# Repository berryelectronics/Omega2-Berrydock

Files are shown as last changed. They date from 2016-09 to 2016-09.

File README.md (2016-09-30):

# Berrydock Mini



The first one of the series, small but packs a bunch of stuff!
* Onboard Ethernet Jack with Passive PoE cabality (up to 24V)
* Onboard Lithium battery connector with 5V Booster and Charging circuit integrated
* Pinout to most of the GPIO
* Feedback to the Omega2 for when the battery is running low or when it is fully charged
* Onboard USB-to-Serial Converter (CP2102)
* Only 5x5cm in size!

Some renders of the PCB

Front side of the PCB Render

Back side of the PCB

The Schematic can also be viewed inside the project folder

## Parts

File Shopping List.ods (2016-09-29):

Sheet: BoM One Piece
Type | Value/Name | Amount | Price One | Price All | Zwischensumme
IC | ACT4088 | 1 | 0,31 € | 0,31 €
IC | DW01-P | 1 | 0,04 € | 0,04 €
IC | FS8205A | 1 | 0,04 € | 0,04 €
IC | MCP73831 | 1 | 0,11 € | 0,11 €
IC | L6920DCTR | 1 | 0,55 € | 0,55 €
IC | USBLC6-2 | 2 | 0,18 € | 0,36 €
IC | H1260NL | 1 | 0,27 € | 0,27 €
IC | TD6811 | 1 | 0,16 € | 0,16 €
IC | CP2102 | 1 | 0,85 € | 0,85 € | 2,69 €
Resistor | 10K 0603 | 8 | 0,00 € | 0,02 €
Resistor | 150K 0603 | 1 | 0,00 € | 0,00 €
Resistor | 28.7K 0603 | 1 | 0,00 € | 0,00 €
Resistor | 1K 0603 | 3 | 0,00 € | 0,01 €
Resistor | 2K 0603 | 5 | 0,00 € | 0,02 €
Resistor | 20K 0603 | 1 | 0,00 € | 0,00 €
Resistor | 200K 0603 | 1 | 0,00 € | 0,00 €
Resistor | 1M 0603 | 1 | 0,00 € | 0,00 €
Resistor | 3K 0603 | 5 | 0,00 € | 0,02 €
Resistor | 75R 0603 | 2 | 0,00 € | 0,01 €
Resistor | 0R 0603 | 4 | 0,00 € | 0,02 €
Resistor | 100R 0603 | 1 | 0,00 € | 0,00 €
Resistor | 49.9R 0603 | 4 | 0,01 € | 0,02 € | 0,13 €
Capacitor | 10uF 50V 1206 | 4 | 0,02 € | 0,08 €
Capacitor | 22nF 0603 | 1 | 0,00 € | 0,00 €
Capacitor | 4.7uF 0603 | 6 | 0,02 € | 0,12 €
Capacitor | 100nF 0603 | 7 | 0,00 € | 0,03 €
Capacitor | 1uF 0603 | 2 | 0,01 € | 0,02 €
Capacitor | 1nF 2kV 1206 | 1 | 0,03 € | 0,03 €
Capacitor | 47uF 0805 | 1 | 0,02 € | 0,02 € | 0,30 €
Inductor | 10uF 1A CD43 | 1 | 0,08 € | 0,08 €
Inductor | 4.7uH 1A CD32 | 2 | 0,06 € | 0,12 € | 0,20 €
Diode | M7 1N4007 | 1 | 0,01 € | 0,01 €
Diode | D240A-13-F | 1 | 0,17 € | 0,17 €
Diode | LED Red 0805 | 2 | 0,01 € | 0,02 € | 0,20 €
Fuse | 1A 8V 1812 | 1 | 0,10 € | 0,10 € | 0,10 €
Connector | 2mm Female 40 Pin | 1 | 0,17 € | 0,17 €
Connector | 2.54mm Male 40 Pin | 1 | 0,55 € | 0,55 €
Connector | S2B-PH-SM4-TB JST LiPo | 1 | 0,25 € | 0,25 €
Connector | Ethernet Jack | 1 | 0,24 € | 0,24 €
Connector | USB Type A 90 Degrees | 1 | 0,10 € | 0,10 €
Connector | Micro USB SMD | 1 | 0,20 € | 0,20 € | 1,51 €
Miscellanious | SMD Tactile Switch | 1 | 0,05 € | 0,05 €
Miscellanious | SMD Switch | 1 | 0,10 € | 0,10 € | 0,15 €
PCB | 5x5cm | 1 | 2,00 € | 2,00 € | 2,00 €
 |  |  |  | 7,28 €
 |  |  | Gesamt | 8,00 €

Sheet: Order List (x20)
Type | Name | Amount | Price All | Price One | Link
IC | ACT4088 | 10 | 3,09 | 0,309 | https://de.aliexpress.com/item/10PCS-LOT-ACT4088US-T-ACT4088US-ACT4088-SOT23-6-DC-DC-chip/32698768524.html
IC | FS8205 | 50 | 1,65 | 0,033 | https://de.aliexpress.com/item/10PCS-free-shipping-100-new-original-new-original-DW01D-FS8205-SOT23-6-lithium-battery-protection-IC/1676832825.html
IC | DW01 | 50 | 1,65 | 0,033 | https://de.aliexpress.com/item/10PCS-free-shipping-100-new-original-new-original-DW01D-FS8205-SOT23-6-lithium-battery-protection-IC/1676832825.html
IC | MCP73831 | 20 | 2,08 | 0,104 | https://de.aliexpress.com/item/20PCS-MCP73831T-2ACI-OT-MCP73831T-2ACI-SOT-23-5-MCP73831/32239785824.html
IC | L6920DCTR | 10 | 5,43 | 0,543 | https://de.aliexpress.com/item/10-PCS-lot-L6920-L6920D-L6920DCTR-prints-6920-ST/32675590284.html
IC | USBLC6-2 | 20 | 3,5 | 0,175 | https://de.aliexpress.com/item/Free-shipping-20pcs-lot-SMT-SOT-23-6-chips-USBLC6-2-new-original/32518640742.html
IC | H1260NL | 20 | 5,25 | 0,2625 | https://de.aliexpress.com/item/H1260NL-genuine-new-original-100-PULSE-SMT-SOP16/32519209228.html
IC | TD6811 | 20 | 3,17 | 0,1585 | https://de.aliexpress.com/item/20PCS-TD6811-6811-SOT23-5/32463696690.html
IC | CP2102 | 10 | 8,41 | 0,841 | https://de.aliexpress.com/item/Free-Shipping-10pcs-USB-interface-control-chip-CP2102-QFN28/1062388544.html
Resistor | 10K 0603 | 100 | 0,23 | 0,0023 | https://de.aliexpress.com/item/0603-SMD-Resistor-1-10K-ohm-5000pcs-lot/32308120947.html
Resistor | 150K 0603 | 100 | 0,23 | 0,0023 | https://de.aliexpress.com/item/0603-SMD-Resistor-1-150K-ohm-5000pcs-lot/32307046476.html
Resistor | 28.7K 0603 | 100 | 0,23 | 0,0023 | https://de.aliexpress.com/item/0603-SMD-Resistor-1-28-7K-ohm-5000pcs-lot/32306337804.html
Resistor | 1K 0603 | 100 | 0,23 | 0,0023 | https://de.aliexpress.com/item/0603-SMD-Resistor-1-1K-ohm-5000pcs-lot/32306337400.html
Resistor | 2K 0603 | 100 | 0,23 | 0,0023 | https://de.aliexpress.com/item/0603-SMD-Resistor-1-2K-ohm-5000pcs-lot/32308160767.html
Resistor | 20K 0603 | 100 | 0,23 | 0,0023 | https://de.aliexpress.com/item/0603-SMD-Resistor-1-20K-ohm-5000pcs-lot/32307054013.html
Resistor | 200K 0603 | 100 | 0,23 | 0,0023 | https://de.aliexpress.com/item/0603-SMD-Resistor-1-200K-ohm-5000pcs-lot/32308144804.html
Resistor | 1M 0603 | 100 | 0,23 | 0,0023 | https://de.aliexpress.com/item/0603-SMD-Resistor-1-1M-ohm-5000pcs-lot/32307407217.html
Resistor | 3K 0603 | 100 | 0,23 | 0,0023 | https://de.aliexpress.com/item/0603-SMD-Resistor-1-3K-ohm-5000pcs-lot/32308160800.html
Resistor | 75R 0603 | 100 | 0,35 | 0,0035 | https://de.aliexpress.com/item/Free-shipping-500pcs-RES-ORIGINAL-SMD-Resistor-1-0603-75R-75-OHMS-chip-resistor-1-10w/32260381157.html
Resistor | 0R 0603 | 100 | 0,35 | 0,0035 | https://de.aliexpress.com/item/Free-shipping-100pcs-RES-ORIGINAL-SMD-Resistor-1-0603-0R-0-OHMS-chip-resistor-1-10W/32506782798.html
Resistor | 100R 0603 | 100 | 0,35 | 0,0035 | https://de.aliexpress.com/item/Free-shipping-500pcs-RES-ORIGINAL-SMD-Resistor-1-0603-100R-100-OHMS-chip-resistor-1-10W/32262485248.html
Resistor | 49.9R 0603 | 100 | 0,55 | 0,0055 | https://de.aliexpress.com/item/100pcs-lot-SMD-Chip-Resistor-1-0603-49-9R-49-9-OHMS-1-10W-100-YAGEO/32571843113.html
Capacitor | 10uF 50V 1206 | 200 | 2,8 | 0,014 | https://de.aliexpress.com/item/Free-Shipping-1206-smd-capacitor-3216-10UF-106-50V/1889689228.html
Capacitor | 22nF 0603 | 100 | 0,34 | 0,0034 | https://de.aliexpress.com/item/100pcs-lot-22nF-Y5V-Error-20-50V-0603-smd-capacitor/32319892152.html
Capacitor | 4.7uF 0603 | 100 | 1,23 | 0,0123 | https://de.aliexpress.com/item/100pcs-lot-4-7uF-X5R-Error-10-16V-0603-smd-capacitor/32319876555.html
Capacitor | 100nF 0603 | 100 | 0,34 | 0,0034 | https://de.aliexpress.com/item/100pcs-lot-100nF-X7R-Error-10-50V-0603-smd-capacitor/32318089455.html
Capacitor | 1uF 0603 | 100 | 0,92 | 0,0092 | https://de.aliexpress.com/item/100pcs-lot-1uF-X5R-Error-10-16V-0603-smd-capacitor/32319876550.html
Capacitor | 1nF 2kV 1206 | 100 | 2,45 | 0,0245 | https://de.aliexpress.com/item/100pcs-lot-1nF-X7R-Error10-2KV-1206-smd-capacitor/32319991021.html
Capacitor | 47uF 0805 | 100 | 1,86 | 0,0186 | https://de.aliexpress.com/item/Free-shipping-005-SMD-capacitor-47uf-16V-476K-100PCS/32374775645.html
Inductor | 10uF 1A CD43 | 50 | 3,74 | 0,0748 | https://de.aliexpress.com/item/50PCS-LOT-CD43-10UH-100-1A-Wire-Wound-Chip-Inductors/32310490700.html
Inductor | 4.7uH 1A CD32 | 100 | 5,7 | 0,057 | https://de.aliexpress.com/item/Free-ship-100PCS-High-Quality-CD32-4-7UH-4R7-1A-Winding-SMD-Power-Inductor-Wire-Wound/32600295471.html
Diode | M7 1N4007 | 50 | 0,48 | 0,0096 | https://de.aliexpress.com/item/Free-shiiping-50PCS-DIODE-M7-1N4007-SMD-1A-1000V-Rectifier-Diode-A027/32586502630.html
Diode | D240A-13-F | 20 | 3,29 | 0,1645 | https://de.aliexpress.com/item/B240A-B240A-13-F-only-do-import-new-original-spot-ICQ3/32715096810.html
Diode | LED Red 0805 | 100 | 0,9 | 0,009 | https://de.aliexpress.com/item/Smart-Electronics-100pcs-lot-Super-Bright-0805-Red-Lighting-SMD-Led-Diode-620-625nm-120-150MCD/32592136800.html
Fuse | 1A 8V 1812 | 100 | 8,32 | 0,0832 | https://de.aliexpress.com/item/1812-8V-1A-1-1A-SMD-patch-self-recovery-fuse-all/32600969766.html
Connector | 2mm Female 40 Pin | 10 | 1,63 | 0,163 | https://de.aliexpress.com/item/10PCS-LOT-Female-Pin-Header-Strip-1-40-Pin-2mm-Single-Row-Female-Pin-Header/32692137257.html
Connector | 2.54mm Male 40 Pin | 10 | 0,55 | 0,055 | https://de.aliexpress.com/item/Free-Shipping-40Pin-2-54mm-male-Single-Row-40P-single-Row-20pcs-40-pins-pin-header/1702073435.html
Connector | S2B-PH-SM4-TB JST LiPo | 50 | 11,57 | 0,2314 | https://de.aliexpress.com/item/S2B-PH-SM4-TB-LF-SN/32658848052.html
Connector | Ethernet Jack | 10 | 2,36 | 0,236 | https://de.aliexpress.com/item/10Pcs-Female-RJ45-Ethernet-PCB-Modular-Terminal-Socket-Connector-Jack/32275923385.html
Connector | USB Type A 90 Degrees | 50 | 4,01 | 0,0802 | https://de.aliexpress.com/item/A-Female-USB-socket-looper-USB-A-type-connector-female-90-degree-bend-feet-Free-shipping/32712708223.html
Connector | Micro USB SMD | 20 | 3,8 | 0,19 | https://de.aliexpress.com/item/20PCS-SMD-MICRO-MINI-USB-5-Pin-5pin-Female-for-mobile-phone-charging-power-connector/32292625613.html
Miscellanious | SMD Tactile Switch | 50 | 2,03 | 0,0406 | https://de.aliexpress.com/item/50PCS-2-4-3-5MM-mini-SMD-MP3-MP4-Key-switch-Push-button-switch-Side-SMD/32691696109.html
Miscellanious | SMD Switch | 50 | 4,99 | 0,0998 | https://de.aliexpress.com/item/50-PCS-DC-50V-0-3A-7-Pin-On-On-2-Position-1P2T-SPDT-SMD-Slide/32304561463.html
 |  |  | 101,21

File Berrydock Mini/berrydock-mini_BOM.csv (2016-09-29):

Reference | Value | Footprint | Count | Datasheet | FootprintLib
U5 | Omega2 | Omega2-Outline | 1 |  | Omega2-Berrydock
J1 | RJ45 | RJ45-SHIELDED | 1 |  | Omega2-Berrydock
C10 | 10uF/50V | C_1206 | 1 |  | Capacitors_SMD
D3 | B240A | DO-214AC.SMA | 1 |  | Omega2-Berrydock
L2 | 4.7uH | CD32 | 1 |  | Omega2-Berrydock
U8 | ACT4088 | SOT-23-6_Handsoldering | 1 |  | TO_SOT_Packages_SMD
R13 | R15 | R29 | R21 | R1 | R5 | R4 | R24 | 10K | R_0603_HandSoldering | 8 |  | Resistors_SMD
C13 | 22nF | C_0603 | 1 |  | Capacitors_SMD
R20 | 150K | R_0603_HandSoldering | 1 |  | Resistors_SMD
R19 | 28.7K | R_0603_HandSoldering | 1 |  | Resistors_SMD
C14 | C11 | C17 | C22 | C23 | 4.7uF | C_0603 | 5 |  | Capacitors_SMD
P3 | CONN_01X04 | PWR-SELECT | 1 |  | Omega2-Berrydock
U12 | DW01-P | SOT-23-6_Handsoldering | 1 |  | TO_SOT_Packages_SMD
U11 | FS8205A | TSSOP8 | 1 |  | Omega2-Berrydock
C15 | C12 | C21 | C4 | C5 | C19 | C20 | 100nF | C_0603 | 7 |  | Capacitors_SMD
R25 | 100R | R_0603_HandSoldering | 1 |  | Resistors_SMD
R18 | R23 | R10 | 1K | R_0603_HandSoldering | 3 |  | Resistors_SMD
U9 | MCP73831 | SOT-23-5 | 1 |  | TO_SOT_Packages_SMD
R16 | R27 | R36 | R35 | 2K | R_0603_HandSoldering | 4 |  | Resistors_SMD
D4 | D1 | Led_Small | LED_0805 | 2 |  | LEDs
U10 | L6920DC | MSOP8 | 1 |  | Omega2-Berrydock
L3 | 10uH | CD43 | 1 |  | Omega2-Berrydock
R14 | 20K | R_0603_HandSoldering | 1 |  | Resistors_SMD
C16 | 47uF | C_0805 | 1 |  | Capacitors_SMD
R17 | 200K | R_0603_HandSoldering | 1 |  | Resistors_SMD
P5 | USB_OTG | USB_Micro-B | 1 |  | Connect
U13 | U14 | USBLC6-2 | SOT32-6L | 2 |  | Omega2-Berrydock
R28 | R34 | 1M | R_0603_HandSoldering | 2 |  | Resistors_SMD
F1 | 1A/8V | FUSE-1812 | 1 |  | Omega2-Berrydock
SW1 | SWITCH_INV | SMD-SLIDESWITCH | 1 |  | Omega2-Berrydock
SW2 | BUTTON | SMD-BUTTON-2x4x3,5 | 1 |  | Omega2-Berrydock
R26 | R37 | R38 | 3K | R_0603_HandSoldering | 3 |  | Resistors_SMD
U4 | H1260NL | HL1260NL | 1 |  | Omega2-Berrydock
C8 | C18 | 1uF | C_0603 | 2 |  | Capacitors_SMD
R8 | R6 | R7 | R9 | 49.9R | R_0603 | 4 |  | Resistors_SMD
R12 | R11 | 75R | R_0603 | 2 |  | Resistors_SMD
C9 | 1nF/2kV | C_1206 | 1 |  | Capacitors_SMD
D2 | 1N4007-SMD | DO-214AC.SMA | 1 |  | Omega2-Berrydock
P6 | USB_A | USB_A | 1 |  | Connect
R32 | R33 | R30 | R31 | 0R | R_0603_HandSoldering | 4 |  | Resistors_SMD
U3 | TD6811 | SOT-23-5 | 1 |  | TO_SOT_Packages_SMD
L1 | 4.7uH/1A | CD32 | 1 |  | Omega2-Berrydock
C1 | C7 | 10uF | C_1206 | 2 |  | Capacitors_SMD
P4 | CONN_01X03 | JST-RIGHT-ANGLE | 1 |  | Omega2-Berrydock
P1 | CONN_01X16 | Pin_Header_Straight_1x16 | 1 |  | Pin_Headers
P2 | CONN_01X07 | Pin_Header_Straight_1x07 | 1 |  | Pin_Headers
R3 | 2K | R_0603 | 1 |  | Resistors_SMD
R2 | 3K | R_0603 | 1 |  | Resistors_SMD
U1 | CP2102 | QFN-28 | 1 |  | Omega2-Berrydock

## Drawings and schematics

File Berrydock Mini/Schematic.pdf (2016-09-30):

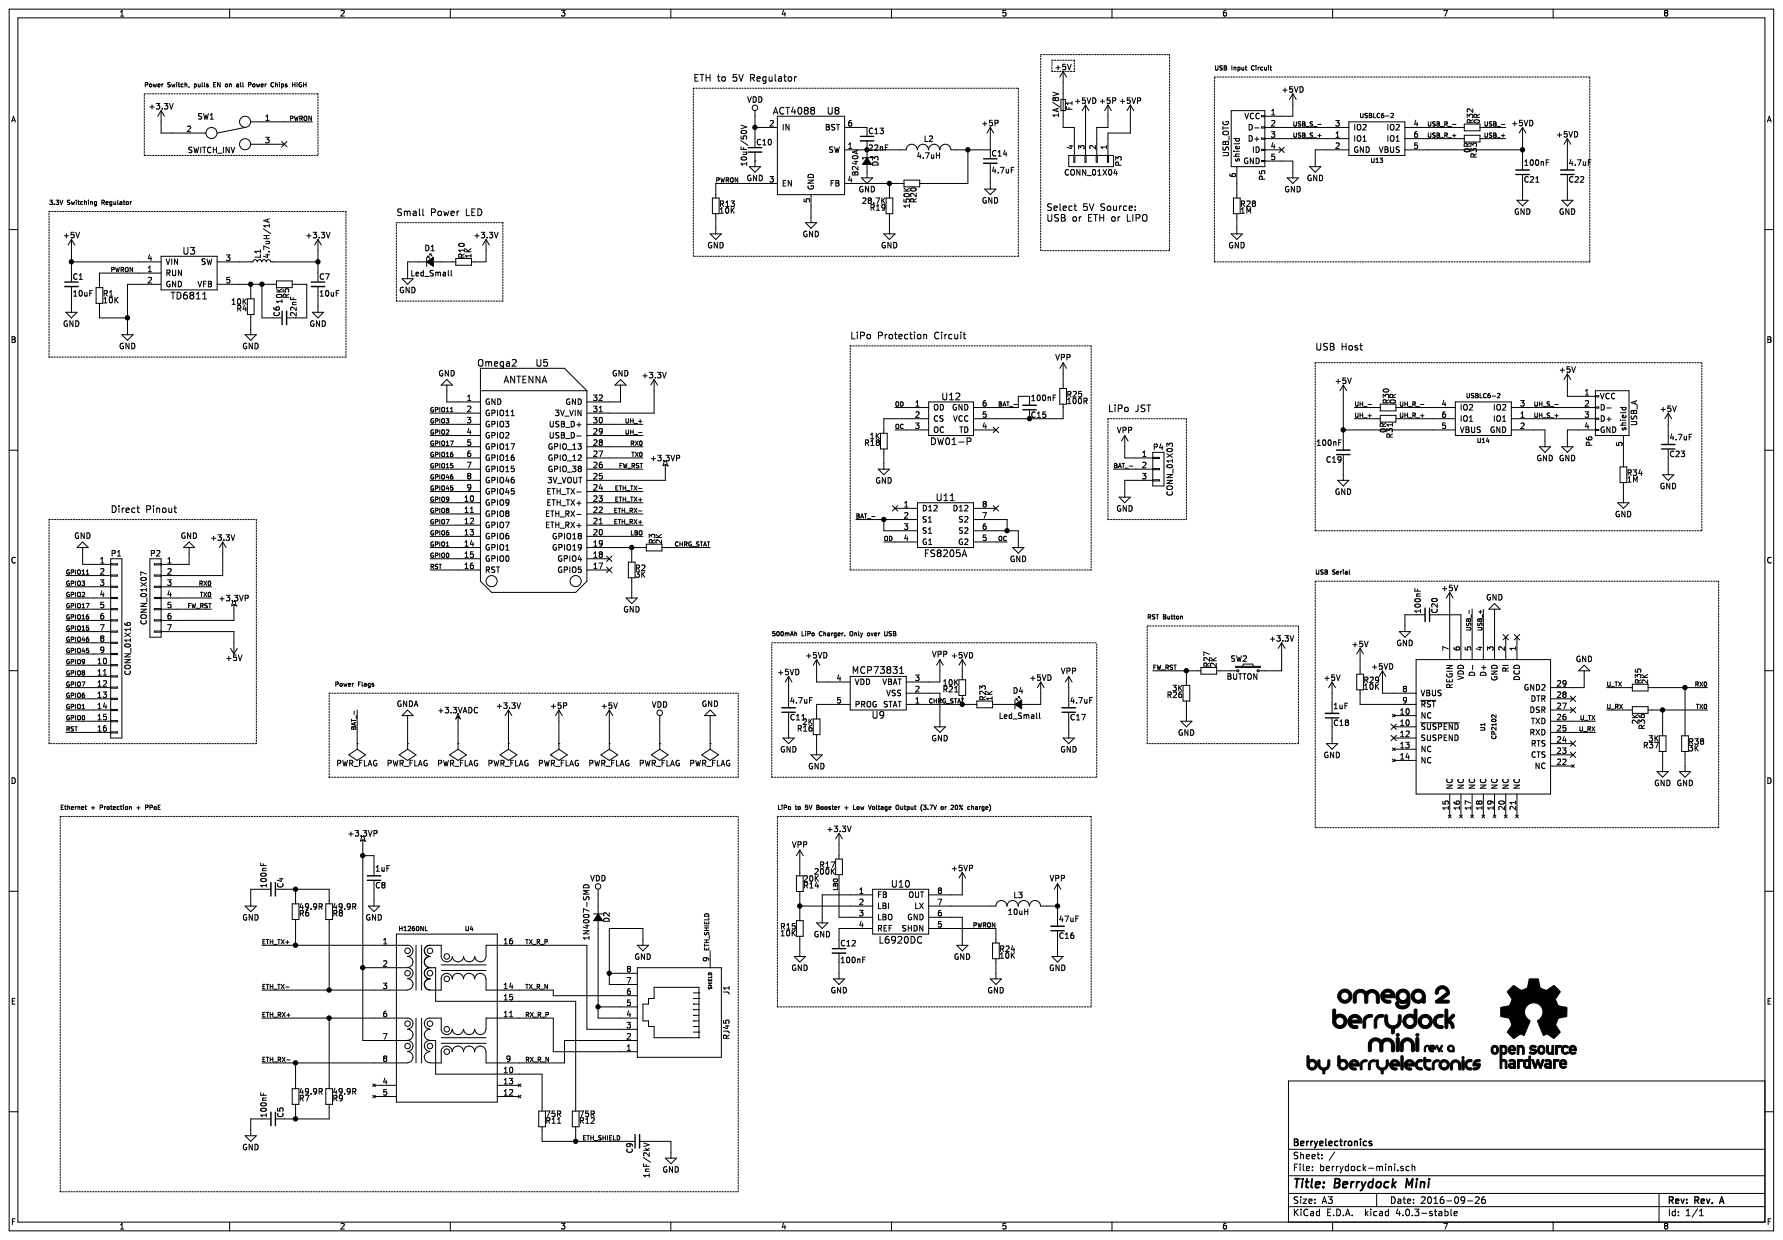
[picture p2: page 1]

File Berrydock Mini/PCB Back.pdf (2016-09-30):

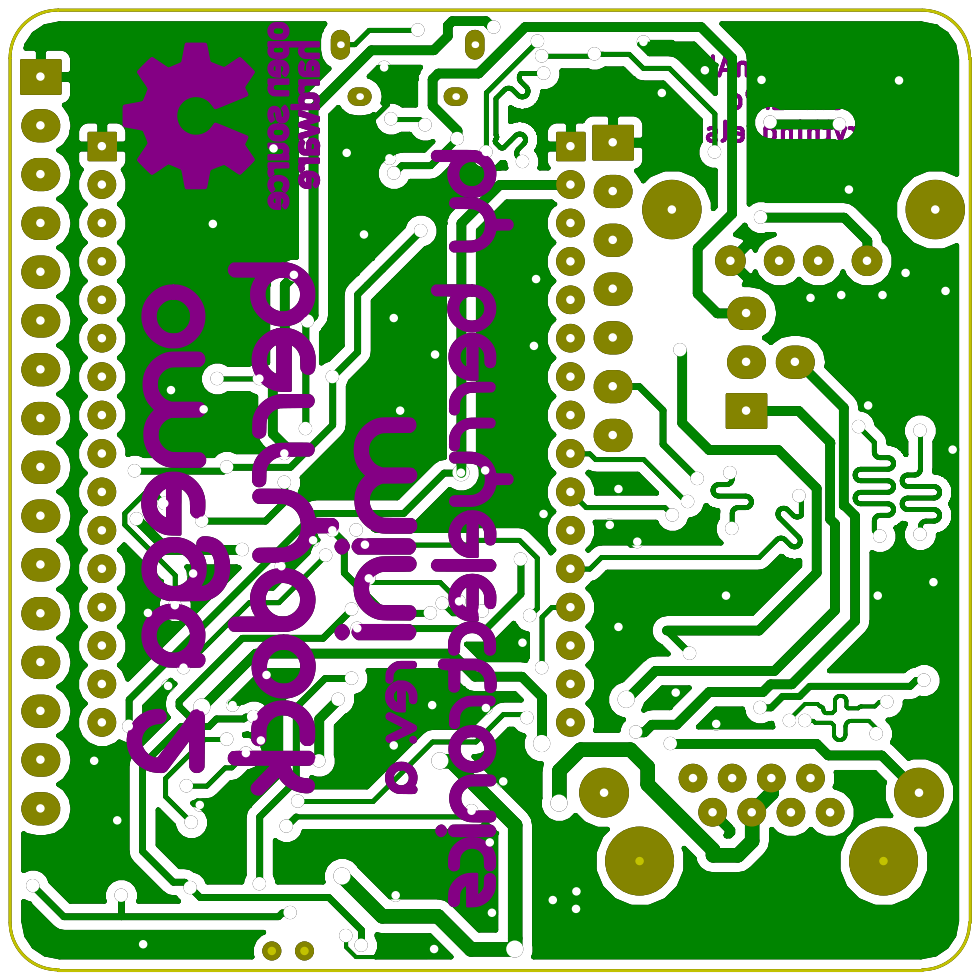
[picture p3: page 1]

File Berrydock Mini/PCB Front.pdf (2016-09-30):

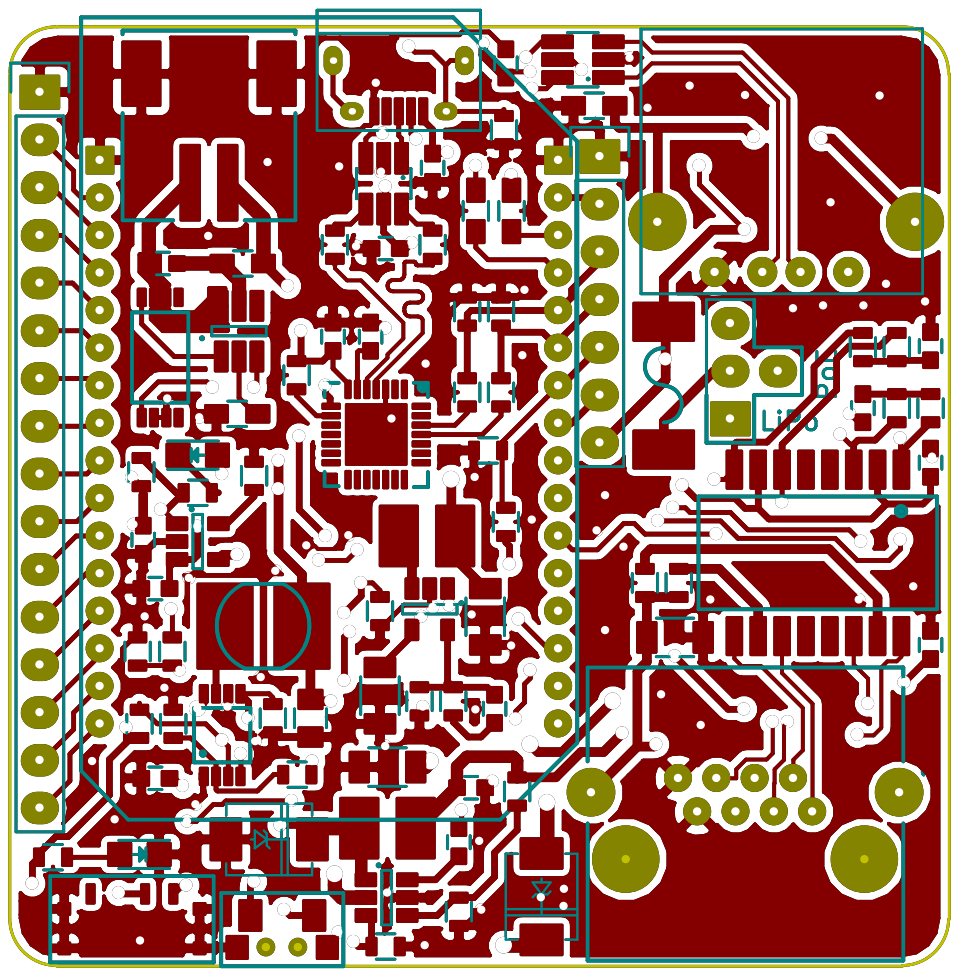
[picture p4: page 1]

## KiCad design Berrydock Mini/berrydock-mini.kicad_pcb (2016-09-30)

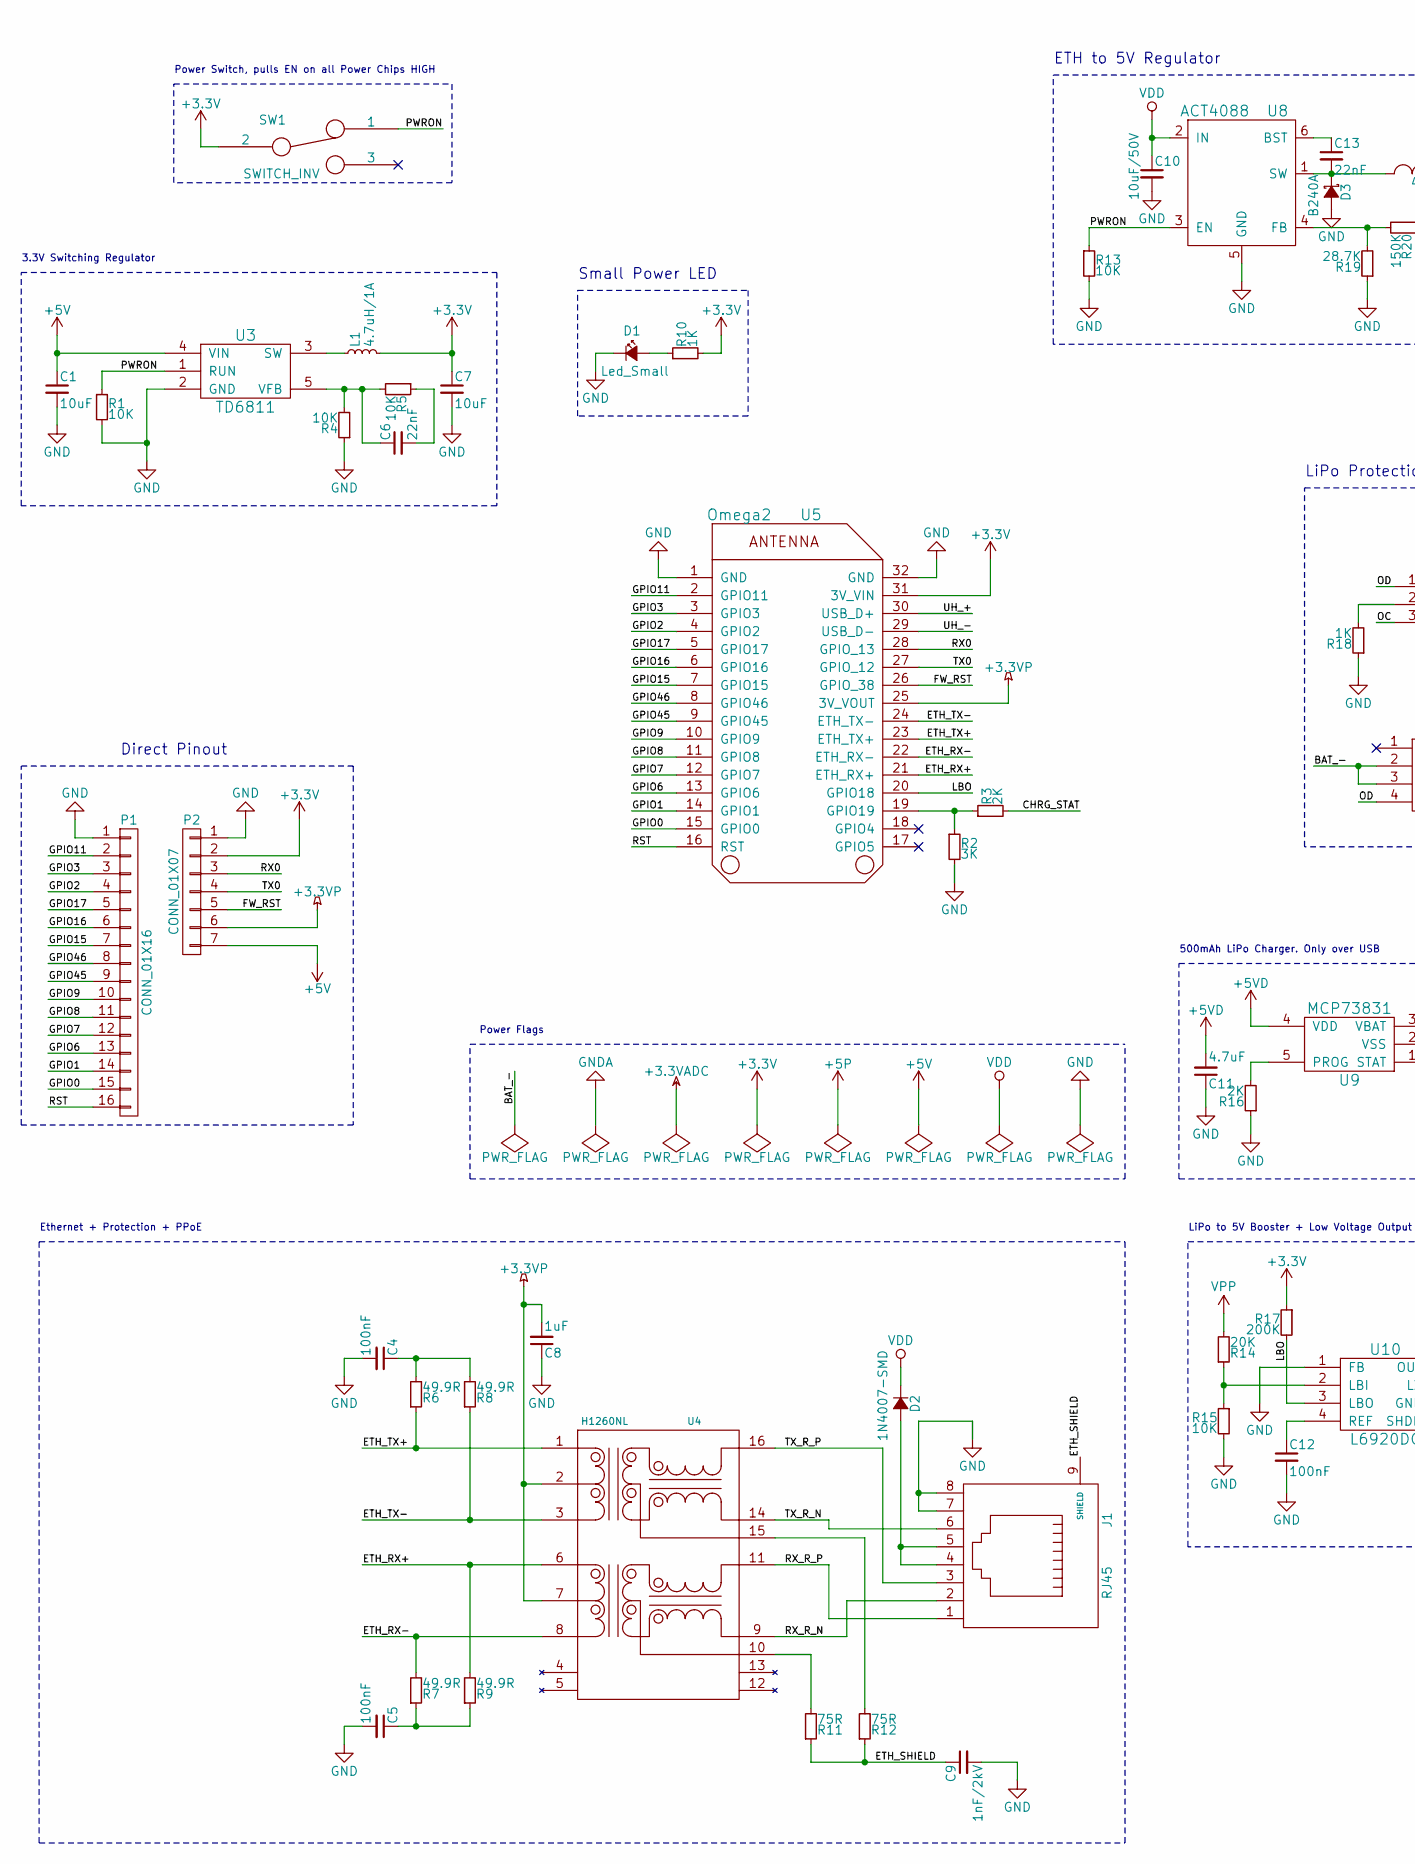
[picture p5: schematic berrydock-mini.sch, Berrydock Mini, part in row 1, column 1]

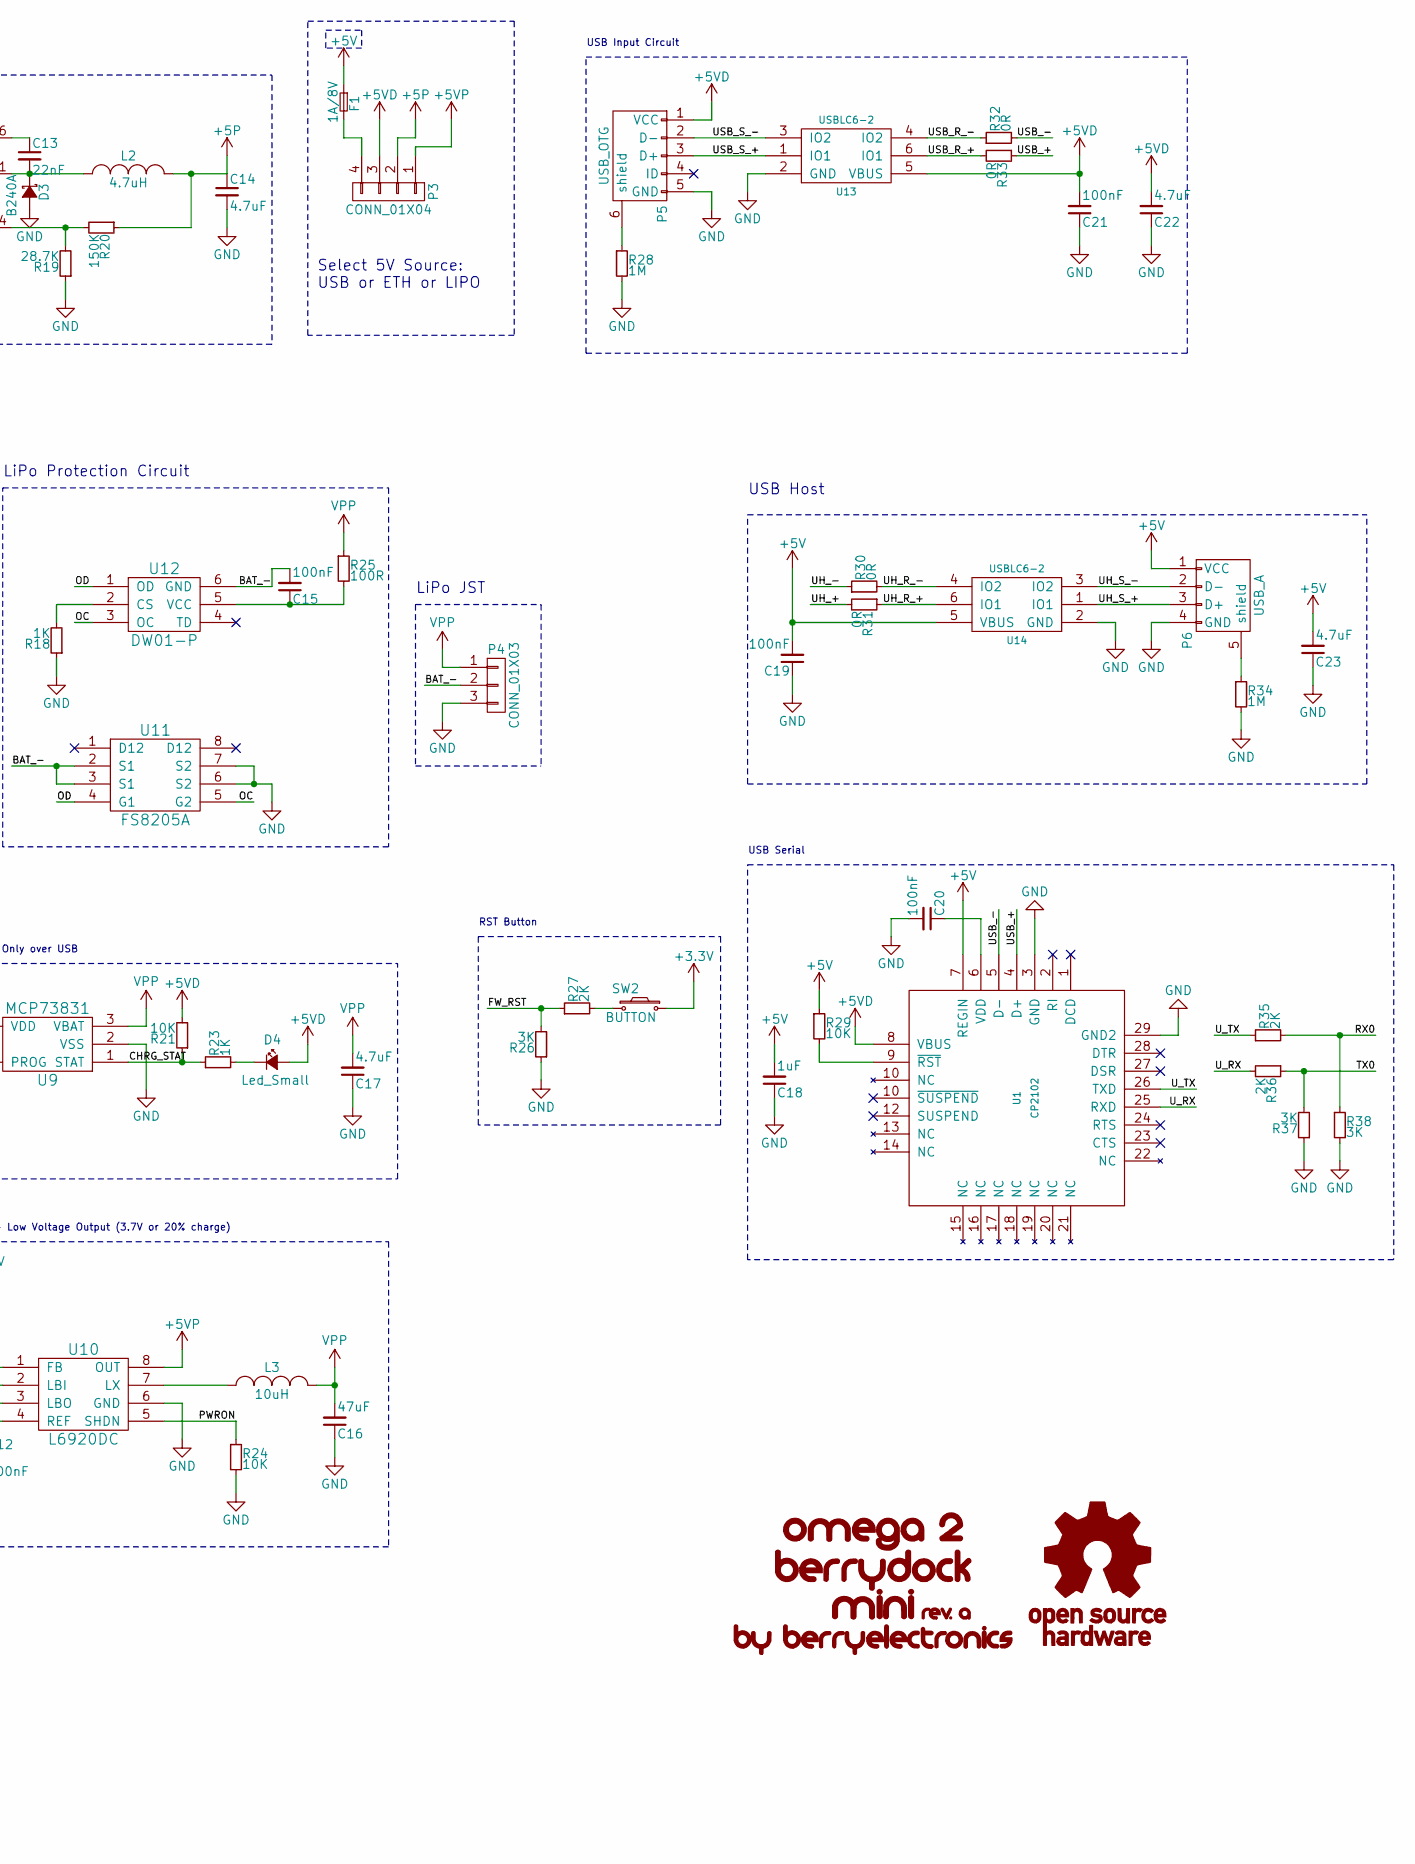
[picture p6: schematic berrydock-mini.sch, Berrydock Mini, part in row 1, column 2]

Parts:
C1, C7: 10uF; C_1206
C4, C5, C12, C15, C19, C20, C21: 100nF; C_0603
C6, C13: 22nF; C_0603
C8, C18: 1uF; C_0603
C9: 1nF/2kV; C_1206
C10: 10uF/50V; C_1206
C11, C14, C17, C22, C23: 4.7uF; C_0603
C16: 47uF; C_0805
D1, D4: Led_Small; LED_0805
D2: 1N4007-SMD; DO-214AC.SMA
D3: B240A; DO-214AC.SMA
F1: 1A/8V; FUSE-1812
G1: SIMPLELOGO; simplelogo
G2: OSHWLOGO; oshwlogo
J1: RJ45; RJ45-SHIELDED
L1: 4.7uH/1A; CD32
L2: 4.7uH; CD32
L3: 10uH; CD43
P1: CONN_01X16; Pin_Header_Straight_1x16
P2: CONN_01X07; Pin_Header_Straight_1x07
P3: CONN_01X04; PWR-SELECT
P4: CONN_01X03; JST-RIGHT-ANGLE
P5: USB_OTG; USB_Micro-B
P6: USB_A
R1, R4, R5, R13, R15, R21, R24, R29: 10K; R_0603
R2, R26, R37, R38: 3K; R_0603
R3, R16, R27, R35, R36: 2K; R_0603
R6, R7, R8, R9: 49.9R; R_0603
R10, R23: 1K; R_0603
R11, R12: 75R; R_0603
R14: 20K; R_0603
R17: 200K; R_0603
R18: 1K; R_0603_HandSoldering
R19: 28.7K; R_0603
R20: 150K; R_0603
R25: 100R; R_0603_HandSoldering
R28: 1M; R_0603
R30, R31: 0R; R_0603_HandSoldering
R32, R33: 0R; R_0603
R34: 1M; R_0603_HandSoldering
SW1: SWITCH_INV; SMD-SLIDESWITCH
SW2: BUTTON; SMD-BUTTON-2x4x3,5
U1: CP2102; QFN-28
U3: TD6811; SOT-23-5
U4: H1260NL; HL1260NL
U5: Omega2; Omega2-Outline
U8: ACT4088; SOT-23-6
U9: MCP73831; SOT-23-5
U10: L6920DC; MSOP8
U11: FS8205A; TSSOP8
U12: DW01-P; SOT-23-6_Handsoldering
U13, U14: USBLC6-2; SOT32-6L

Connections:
+3.3VP: C8.2, P2.6, U4.2, U4.7, U5.25 (3V_VOUT)
+3V3: C7.1, L1.2, P2.2, R10.2, R17.1, SW1.2, SW2.1, U5.31 (3V_VIN)
+5P: C14.1, L2.2, P3.2, R20.1
+5V: C1.1, C18.2, C19.2, C23.2, F1.1, P2.7, P6.1 (VCC), R29.1, U1.7 (REGIN), U3.4 (VIN), U14.5 (VBUS)
+5VD: C11.2, C21.2, C22.2, D4.2 (A), P3.3, P5.1 (VCC), R21.2, U1.8 (VBUS), U9.4 (VDD), U13.5 (VBUS)
+5VP: P3.1, U10.8 (OUT)
/BAT_-: C15.2, P4.2, U11.2 (S1), U11.3 (S1), U12.6 (GND)
/CHRG_STAT: R3.2, R21.1, R23.1, U9.1 (STAT)
/ETH_RX+: R9.2, U4.6, U5.21 (ETH_RX+)
/ETH_RX-: R7.2, U4.8, U5.22 (ETH_RX-)
/ETH_SHIELD: C9.1, J1.9 (SHIELD), R11.1, R12.1
/ETH_TX+: R6.1, U4.1, U5.23 (ETH_TX+)
/ETH_TX-: R8.1, U4.3, U5.24 (ETH_TX-)
/FW_RST: P2.5, R26.2, R27.1, U5.26 (GPIO_38)
/GPIO0: P1.15, U5.15 (GPIO0)
/GPIO1: P1.14, U5.14 (GPIO1)
/GPIO2: P1.4, U5.4 (GPIO2)
/GPIO3: P1.3, U5.3 (GPIO3)
/GPIO6: P1.13, U5.13 (GPIO6)
/GPIO7: P1.12, U5.12 (GPIO7)
/GPIO8: P1.11, U5.11 (GPIO8)
/GPIO9: P1.10, U5.10 (GPIO9)
/GPIO11: P1.2, U5.2 (GPIO11)
/GPIO15: P1.7, U5.7 (GPIO15)
/GPIO16: P1.6, U5.6 (GPIO16)
/GPIO17: P1.5, U5.5 (GPIO17)
/GPIO45: P1.9, U5.9 (GPIO45)
/GPIO46: P1.8, U5.8 (GPIO46)
/LBO: R17.2, U5.20 (GPIO18), U10.3 (LBO)
/OC: U11.5 (G2), U12.3 (OC)
/OD: U11.4 (G1), U12.1 (OD)
/PWRON: R1.1, R13.1, R24.1, SW1.1, U3.1 (RUN), U8.3 (EN), U10.5 (SHDN)
/RST: P1.16, U5.16 (RST)
/RX0: P2.3, R35.2, R38.1, U5.28 (GPIO_13)
/RX_R_N: J1.2, U4.9
/RX_R_P: J1.1, U4.11
/TX0: P2.4, R36.1, R37.2, U5.27 (GPIO_12)
/TX_R_N: J1.6, U4.14
/TX_R_P: J1.3, U4.16
/UH_+: R31.2, U5.30 (USB_D+)
/UH_-: R30.1, U5.29 (USB_D-)
/UH_R_+: R31.1, U14.6 (IO1)
/UH_R_-: R30.2, U14.4 (IO2)
/UH_S_+: P6.3 (D+), U14.1 (IO1)
/UH_S_-: P6.2 (D-), U14.3 (IO2)
/USB_+: R33.1, U1.4 (D+)
/USB_-: R32.2, U1.5 (D-)
/USB_R_+: R33.2, U13.6 (IO1)
/USB_R_-: R32.1, U13.4 (IO2)
/USB_S_+: P5.3 (D+), U13.1 (IO1)
/USB_S_-: P5.2 (D-), U13.3 (IO2)
/U_RX: R36.2, U1.25 (RXD)
/U_TX: R35.1, U1.26 (TXD)
GND: C1.2, C4.2, C5.2, C7.2, C8.1, C9.2, C10.2, C11.1, C12.2, C14.2, C16.1, C17.1, C18.1, C19.1, C20.2, C21.1, C22.1, C23.1, D1.1 (K), D3.2 (A), J1.7, J1.8, P1.1, P2.1, P4.3, P5.5 (GND), P6.4 (GND), R1.2, R2.2, R4.1, R13.2, R15.2, R16.1, R18.1, R19.1, R24.2, R26.1, R28.2, R34.2, R37.1, R38.2, SW1.4, SW2.3, SW2.4, U1.3 (GND), U1.29 (GND2), U3.2 (GND), U5.1 (GND), U5.32 (GND), U8.5 (GND), U9.2 (VSS), U10.1 (FB), U10.6 (GND), U11.6 (S2), U11.7 (S2), U13.2 (GND), U14.2 (GND)
unnamed: C4.1, R6.2, R8.2
unnamed: C5.1, R7.1, R9.1
unnamed: C6.1, R4.2, R5.2, U3.5 (VFB)
unnamed: C6.2, R5.1
unnamed: C12.1, U10.4 (REF)
unnamed: C13.1, U8.6 (BST)
unnamed: C13.2, D3.1 (K), L2.1, U8.1 (SW)
unnamed: C15.1, R25.2, U12.5 (VCC)
unnamed: C20.1, U1.6 (VDD)
unnamed: D1.2 (A), R10.1
unnamed: D2.2 (A), J1.4, J1.5
unnamed: D4.1 (K), R23.2
unnamed: F1.2, P3.4
unnamed: L1.1, U3.3 (SW)
unnamed: L3.1, U10.7 (LX)
unnamed: P5.6 (shield), R28.1
unnamed: P6.5 (shield), R34.1
unnamed: R2.1, R3.1, U5.19 (GPIO19)
unnamed: R11.2, U4.10
unnamed: R12.2, U4.15
unnamed: R14.1, R15.1, U10.2 (LBI)
unnamed: R16.2, U9.5 (PROG)
unnamed: R18.2, U12.2 (CS)
unnamed: R19.2, R20.2, U8.4 (FB)
unnamed: R27.2, SW2.2
unnamed: R29.2, U1.9 (~RST)
VDD: C10.1, D2.1 (K), U8.2 (IN)
VPP: C16.2, C17.2, L3.2, P4.1, R14.2, R25.1, U9.3 (VBAT)

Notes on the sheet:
Select 5V Source: USB or ETH or LIPO
ETH to 5V Regulator
3.3V Switching Regulator
LiPo JST
LiPo Protection Circuit
500mAh LiPo Charger. Only over USB
LiPo to 5V Booster + Low Voltage Output (3.7V or 20% charge)
USB Input Circuit
RST Button
Ethernet + Protection + PPoE
USB Host
Direct Pinout
USB Serial
Power Flags
Power Switch, pulls EN on all Power Chips HIGH
Small Power LED

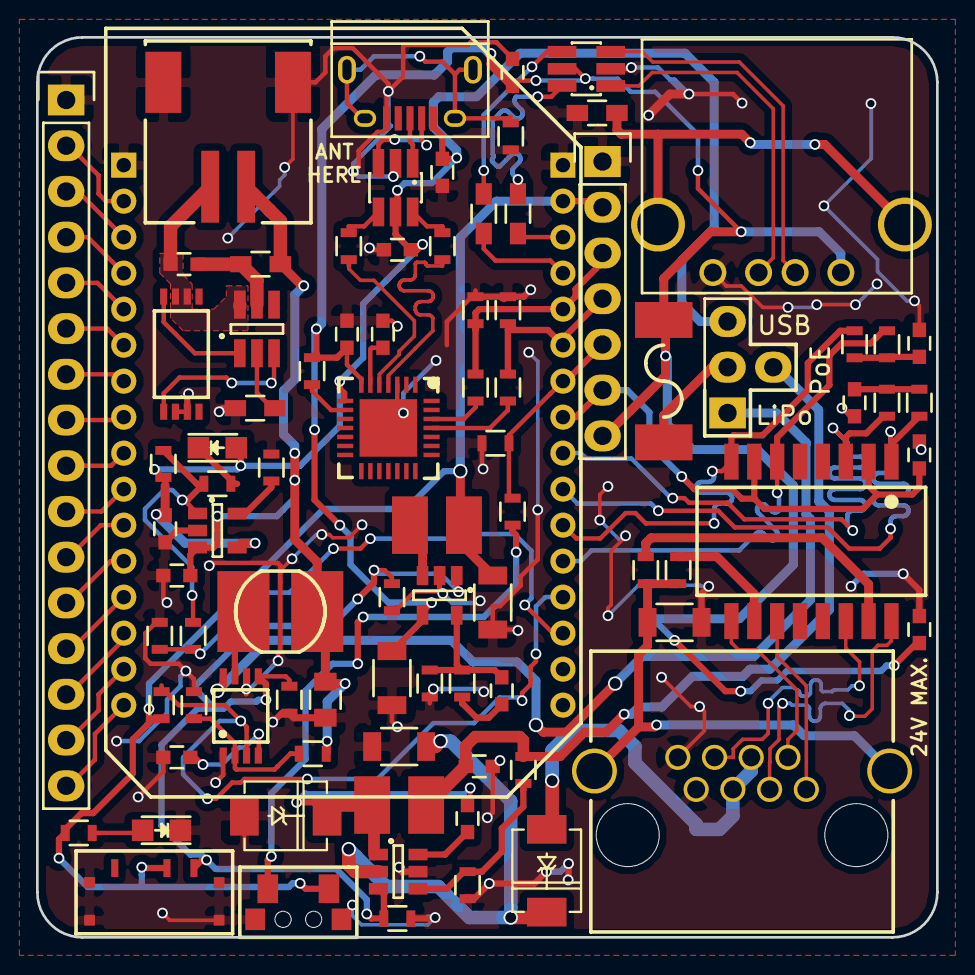
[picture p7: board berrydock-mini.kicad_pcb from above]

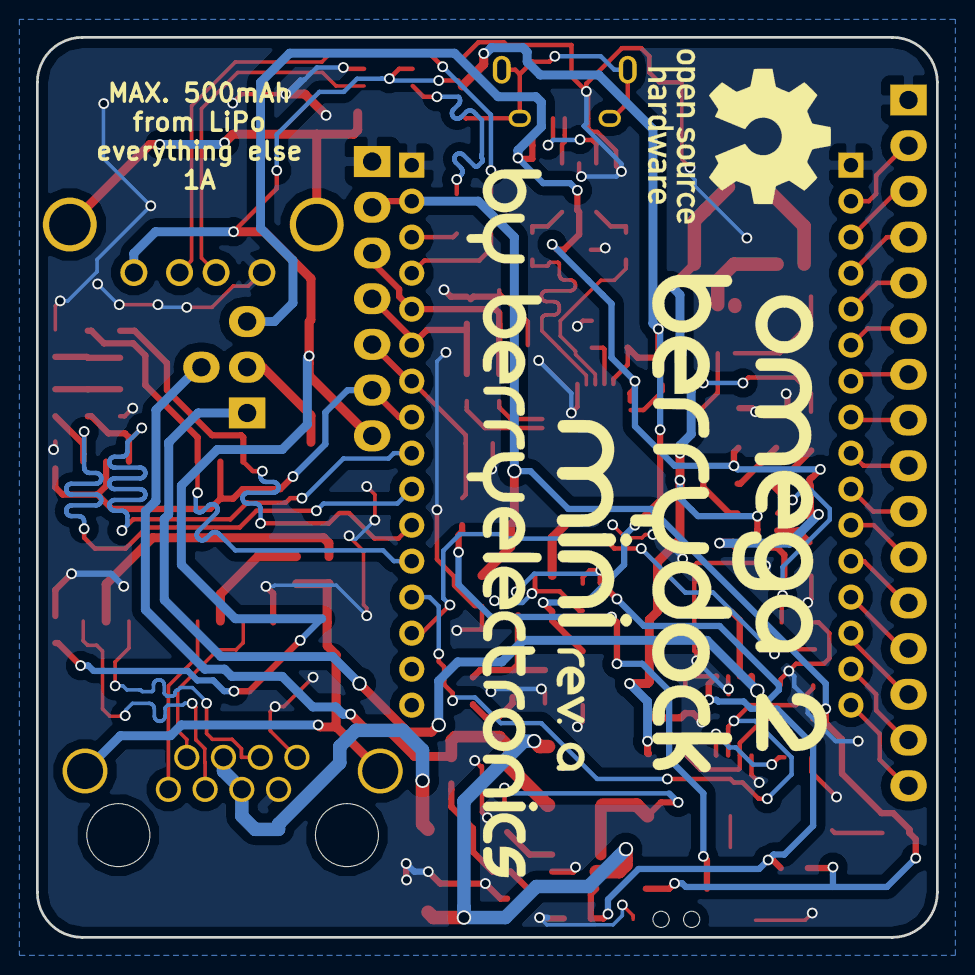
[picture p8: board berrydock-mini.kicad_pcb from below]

Board: 2 copper layers, 50.0 x 50.0 mm, 88 parts (2 on the bottom side), 82 nets.

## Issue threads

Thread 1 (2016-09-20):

Suggestion: Wired network dock

plan44, 2016-09-20:
- mini dock style
- but with Ethernet Jack
- PPoE (passive PoE, just using free wires 4/5 7/8 for power, with down-regulator from 5..24V -> 3.3)
- maybe second Ethernet Jack (if Omega2 pinout will eventually allow that, see [here](https://community.onion.io/topic/987/omega2-documentation/2))

berryelectronics, 2016-09-29:
closed
implemented :)

Closed 2016-09-29.

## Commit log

2016-09-25 created mini doc project, created component library, created omega2 component
    [berrydock-mini.kicad_pcb, berrydock-mini.sch]
2016-09-25 created "shopping" list, created ACT4088 component
    [Shopping List.ods]
2016-09-25 added circuit for ATC4088
    [berrydock-mini.sch]
2016-09-25 Added First part of power Circuit, added lipo protection circuit
    [berrydock-mini.sch]
2016-09-26 75% of schematic finished, power stuff all finished up.
    [berrydock-mini.sch]
2016-09-26 Added CP2102 USB Serial
    [berrydock-mini.sch]
2016-09-26 Added power flags and fixed problems for ERC
    [berrydock-mini.sch]
2016-09-26 Added ADC
    [berrydock-mini.sch]
2016-09-26 added layout text, added schematic PDF
    [berrydock-mini.sch]
2016-09-26 Connected Power Pins to GPIO for charge/low voltage on LiPo
    [berrydock-mini.sch]
2016-09-26 changed some resistor values
    [berrydock-mini.sch]
2016-09-26 added some footprints
    [berrydock-mini.sch]
2016-09-26 changed annontation
    [berrydock-mini.sch]
2016-09-27 Added Github Repo for Footprints
2016-09-27 Added many footprint
    [berrydock-mini.sch]
2016-09-27 fixed errors, new naming of items
    [berrydock-mini.sch]
2016-09-28 Added all footprints
    [berrydock-mini.sch]
2016-09-28 imported everything and laid it out
    [berrydock-mini.kicad_pcb]
2016-09-28 First part of layout done
    [berrydock-mini.kicad_pcb, berrydock-mini.sch]
2016-09-29 laid everything out
    [berrydock-mini.kicad_pcb, berrydock-mini.sch]
2016-09-29 Finished Routing, only BoM and some nice graphics left to do
    [berrydock-mini.kicad_pcb, berrydock-mini.sch]
2016-09-29 Added BoM
    [berrydock-mini_BOM.csv]
2016-09-29 Finished BOM Cost
    [Shopping List.ods, berrydock-mini.kicad_pcb, berrydock-mini.sch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]
2016-09-29 added ods for shopping list
    [Shopping List.ods]
2016-09-29 test generation of gerber
    [berrydock-mini-B.Cu.gbl, berrydock-mini-B.Mask.gbs, berrydock-mini-B.SilkS.gbo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]
2016-09-30 updated schematic
2016-09-30 changed all resistor footprints to 0603, added CE8301A50P component
    [berrydock-mini.kicad_pcb, berrydock-mini.sch]
2016-09-30 moved all footprint descriptions to the fab layer. making pc bit more sexy
    [berrydock-mini.kicad_pcb]
2016-09-30 final touches
    [berrydock-mini.kicad_pcb, berrydock-mini.sch]
2016-09-30 added OSHWLOGO
    [berrydock-mini.kicad_pcb, berrydock-mini.sch]
2016-09-30 OSHW Logo 10x10 Footprint
2016-09-30 new gerbers!
    [berrydock-mini-B.Cu.gbl, berrydock-mini-B.Mask.gbs, berrydock-mini-B.SilkS.gbo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]
2016-09-30 renamed edge layer to .gml
    [berrydock-mini-Edge.Cuts.gm1]
2016-09-30 updated gerbers
    [berrydock-mini-B.Cu.gbl, berrydock-mini-B.Mask.gbs, berrydock-mini-B.SilkS.gbo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]
2016-09-30 updates in pcb
    [berrydock-mini.kicad_pcb]
2016-09-30 PCB Front and Back PDF added, Schematic PDF updates
